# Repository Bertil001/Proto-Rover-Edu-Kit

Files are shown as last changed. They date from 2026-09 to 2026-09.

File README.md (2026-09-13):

# 🚀 P.R.E.K. (Proto-Rover Edu-Kit)

**P.R.E.K.** est une plateforme d'exploration robotique 6x6 open-source conçue pour l'apprentissage et le prototypage avancé. Basé sur un microcontrôleur ESP32 et un châssis "Rocker-Bogie", le rover embarque son propre serveur web tactile, une centrale inertielle 6-axes et une architecture logicielle asynchrone Dual-Core.

---

## ⚙️ Fonctionnalités Principales

* **Châssis Rocker-Bogie :** Suspension mécanique passive permettant de franchir des obstacles asymétriques tout en gardant la plateforme électronique stable.
* **Architecture Dual-Core (MicroPython) :**
  * **Core 0 :** Gestion du réseau, création du point d'accès Wi-Fi, serveur HTTP asynchrone et interface web (UI).
  * **Core 1 :** Cinématique de contrôle moteur (PWM à 1000 Hz), mixage Tank-Drive, rampe d'accélération et calcul trigonométrique de l'assiette.
* **Système Fail-Safe :** Arrêt d'urgence automatique en cas de perte de la trame réseau (délai > 500ms).
* **Interface "Tactical OS" :** IHM web full-responsive hébergée sur l'ESP32, avec vue éclatée SVG interactive et télémétrie en temps réel (Tangage, Roulis, RSSI Wi-Fi).

---

## 🛠️ Matériel Requis (BOM)

* **Microcontrôleur :** 1x ESP32 (WROOM-32)
* **Puissance :** 
  * 1x Batterie Li-Po (7.4V ou 11.1V)
  * 1x Module Buck Converter (12V > 5V) pour isoler le circuit logique
  * 2x Drivers moteur BTS7960 (Pont en H 43A)
* **Motricité :** 6x Micromoteurs N20 avec réducteurs + roues tout-terrain
* **Capteur :** 1x Centrale Inertielle MPU6050 (Accéléromètre / Gyroscope)
* **Sécurité :** Fusible automobile 10A et câblage de puissance adapté

---

## 📂 Arborescence du Projet

* `/src/` : Code source MicroPython embarqué sur l'ESP32.
  * `main.py` : Lanceur Dual-Core.
  * `core0_network.py` : Serveur réseau et code HTML/CSS/JS de l'interface.
  * `core1_motion.py` : Boucle cinématique et gestion matérielle (Moteurs & MPU).
  * `lib_mpu6050.py` : Pilote I2C pour le capteur inertiel.
* `/hardware/` : Fichiers de conception physique (Modèles 3D STEP/STL, Schémas de câblage).
* `/docs/` : Documentation d'ingénierie (Cahier des charges, plans de tests, bilan technique).

---

## 🚀 Démarrage Rapide (Quick Start)

### 1. Déploiement Logiciel
1. Flashez votre ESP32 avec le dernier firmware **MicroPython**.
2. Utilisez un IDE comme [Thonny](https://thonny.org/) ou l'outil **WebREPL** pour transférer l'intégralité du contenu du dossier `/src/` à la racine matérielle de l'ESP32.
3. Redémarrez le microcontrôleur.

### 2. Connexion et Pilotage
Une fois l'ESP32 alimenté, le rover génère son propre réseau autonome :
* **Réseau Wi-Fi (SSID) :** `ProtoRover_AP`
* **Mot de passe Wi-Fi :** *(Réseau ouvert)*
* **URL de l'Interface de Contrôle :** Ouvrez `http://192.168.4.1` sur le navigateur d'un smartphone ou d'un PC.

### 3. Maintenance Sans Fil (OTA)
Le P.R.E.K. intègre le protocole WebREPL pour la mise à jour du code sans câble USB :
* **Adresse WebSocket :** `ws://192.168.4.1:8266`
* **Mot de passe WebREPL :** `rover123`

---

## 📝 Licence
Ce projet est distribué sous la Licence MIT. Consultez le fichier `LICENSE` pour plus d'informations.

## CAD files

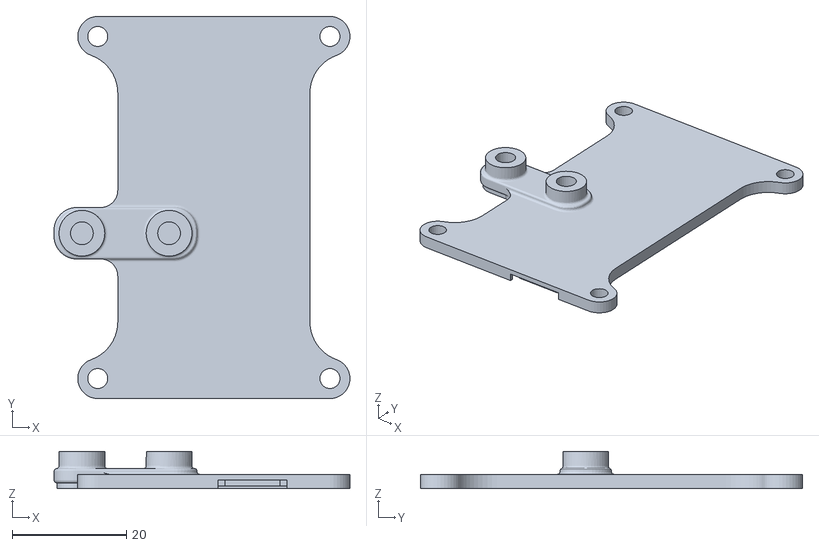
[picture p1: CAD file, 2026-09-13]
hardware/Box_Top_Convertisseur_REVA.stl
51.7 x 66.8 x 6.49

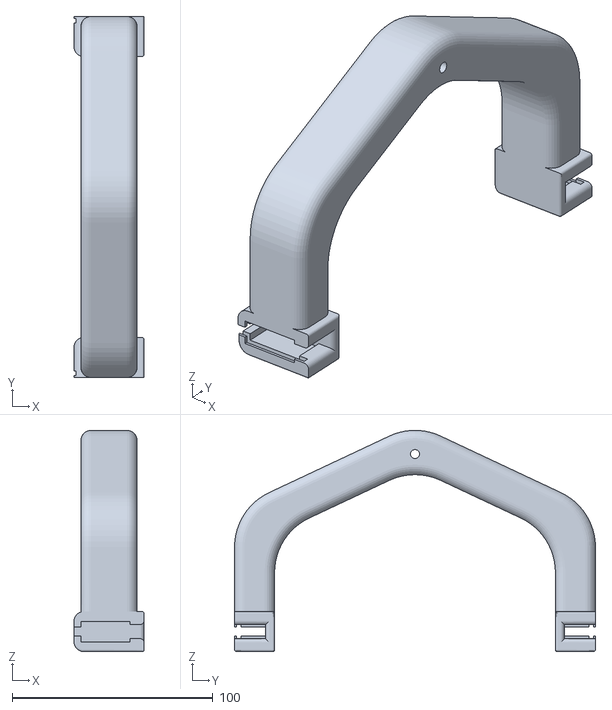
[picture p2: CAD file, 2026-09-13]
hardware/Pivot_Bogie_Left_REVA.stl
35.0 x 180.0 x 110.4

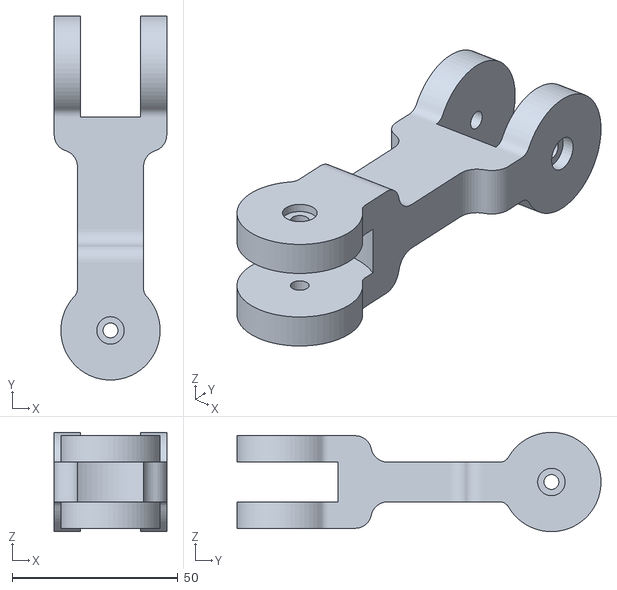
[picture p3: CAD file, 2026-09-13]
hardware/Differential_Link_R_REVA.stl
34.0 x 110.0 x 30.0

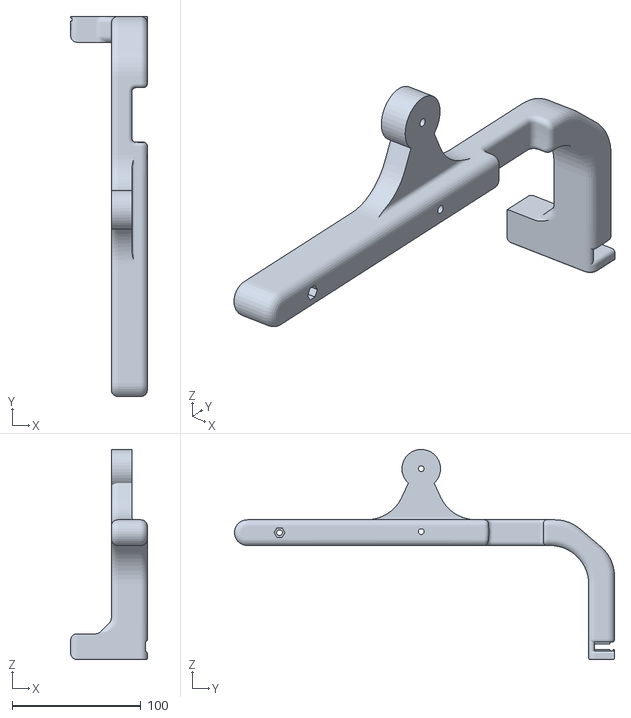
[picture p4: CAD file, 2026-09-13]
hardware/Arm_Rocker_Left_REVA.stl
59.6 x 294.9 x 163.0

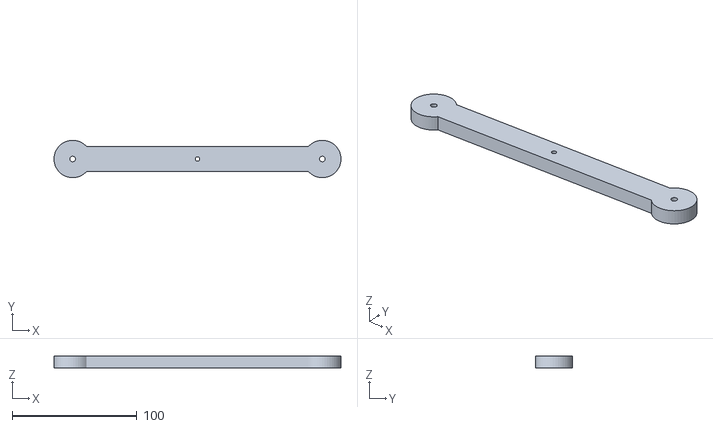
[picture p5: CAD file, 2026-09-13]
hardware/Differential_Bar_REVA.stl
230.3 x 30.0 x 10.0

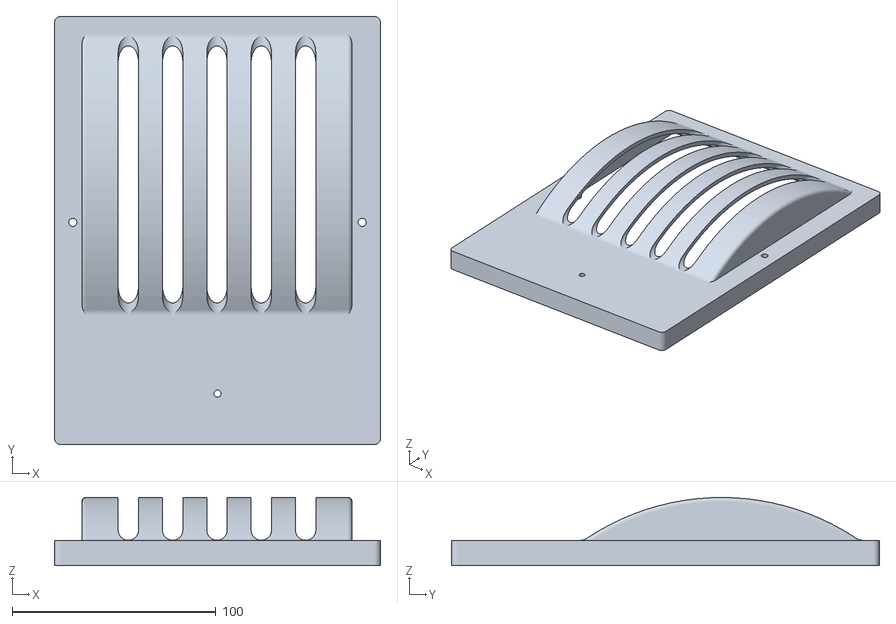
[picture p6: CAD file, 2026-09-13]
hardware/Box_Top_REVA.stl
160.0 x 210.0 x 33.4

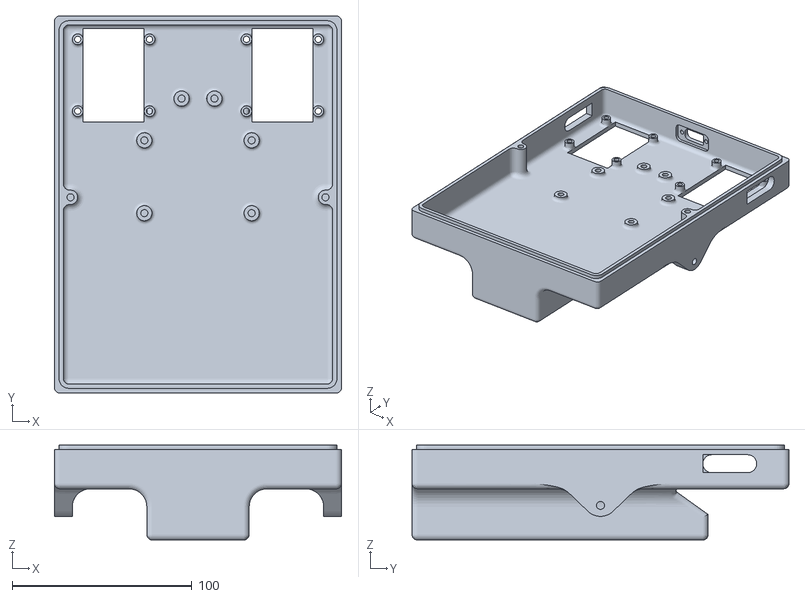
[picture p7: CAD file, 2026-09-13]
hardware/Box_Bottom_REVA.stl
160.0 x 210.0 x 52.9

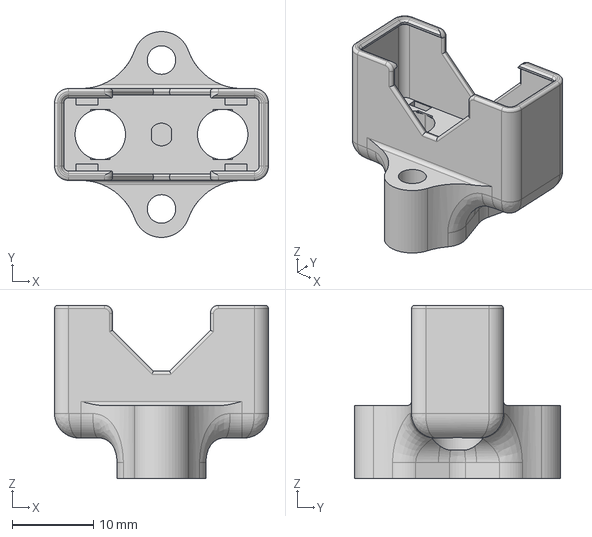
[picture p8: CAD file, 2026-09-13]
hardware/Support_Fusible.step
26.3 x 25.3 x 21.3 mm

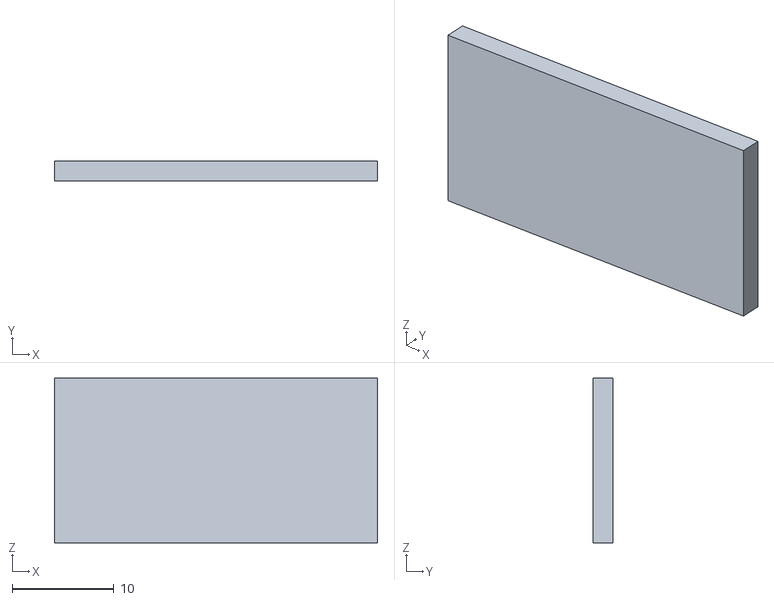
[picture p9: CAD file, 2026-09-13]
hardware/Motor_Retainer_REVA.stl
31.8 x 2.00 x 16.2

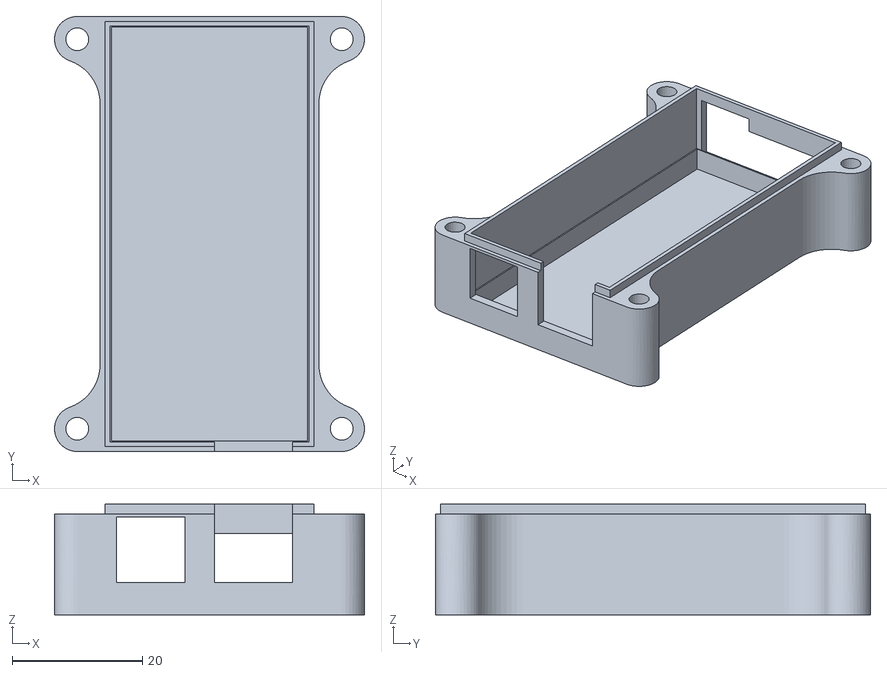
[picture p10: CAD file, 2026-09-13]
hardware/Box_Bottom_Convertisseur.stl
47.6 x 66.8 x 17.0

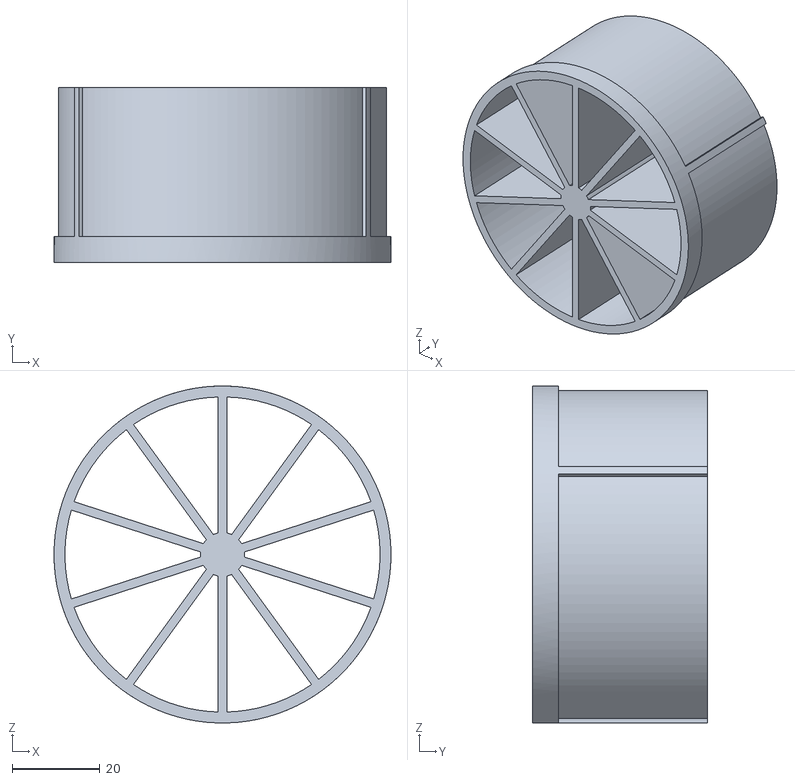
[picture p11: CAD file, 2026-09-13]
hardware/Jante_REVA.stl
76.9 x 40.0 x 76.9

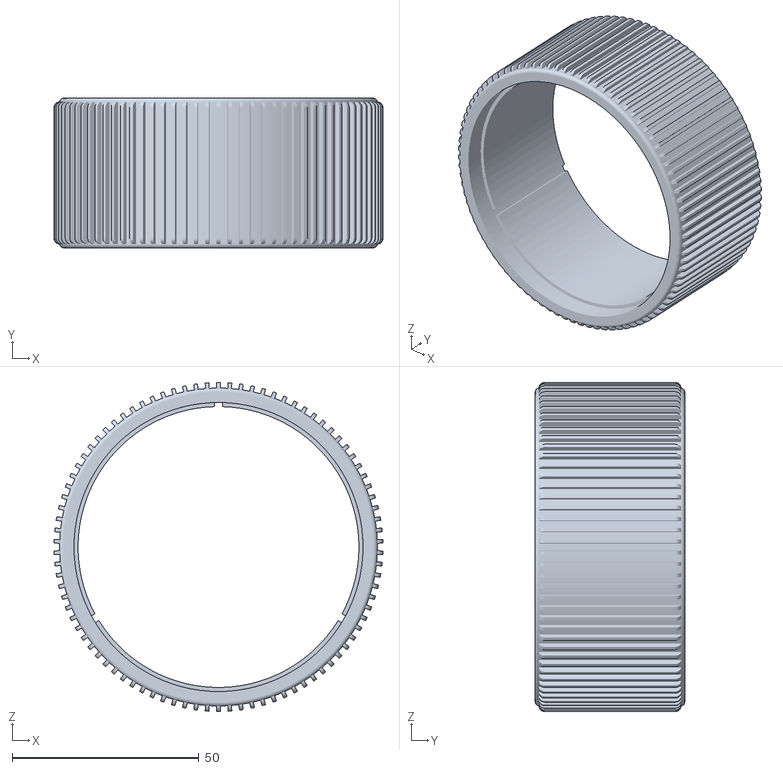
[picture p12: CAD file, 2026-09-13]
hardware/Pneu v11.stl
88.0 x 40.0 x 88.0

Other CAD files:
hardware/Pivot_Bogie_Right_REVA.stl
hardware/Arm_Rocker_Right_REVA.stl
hardware/Differential_Link_L_REVA.stl

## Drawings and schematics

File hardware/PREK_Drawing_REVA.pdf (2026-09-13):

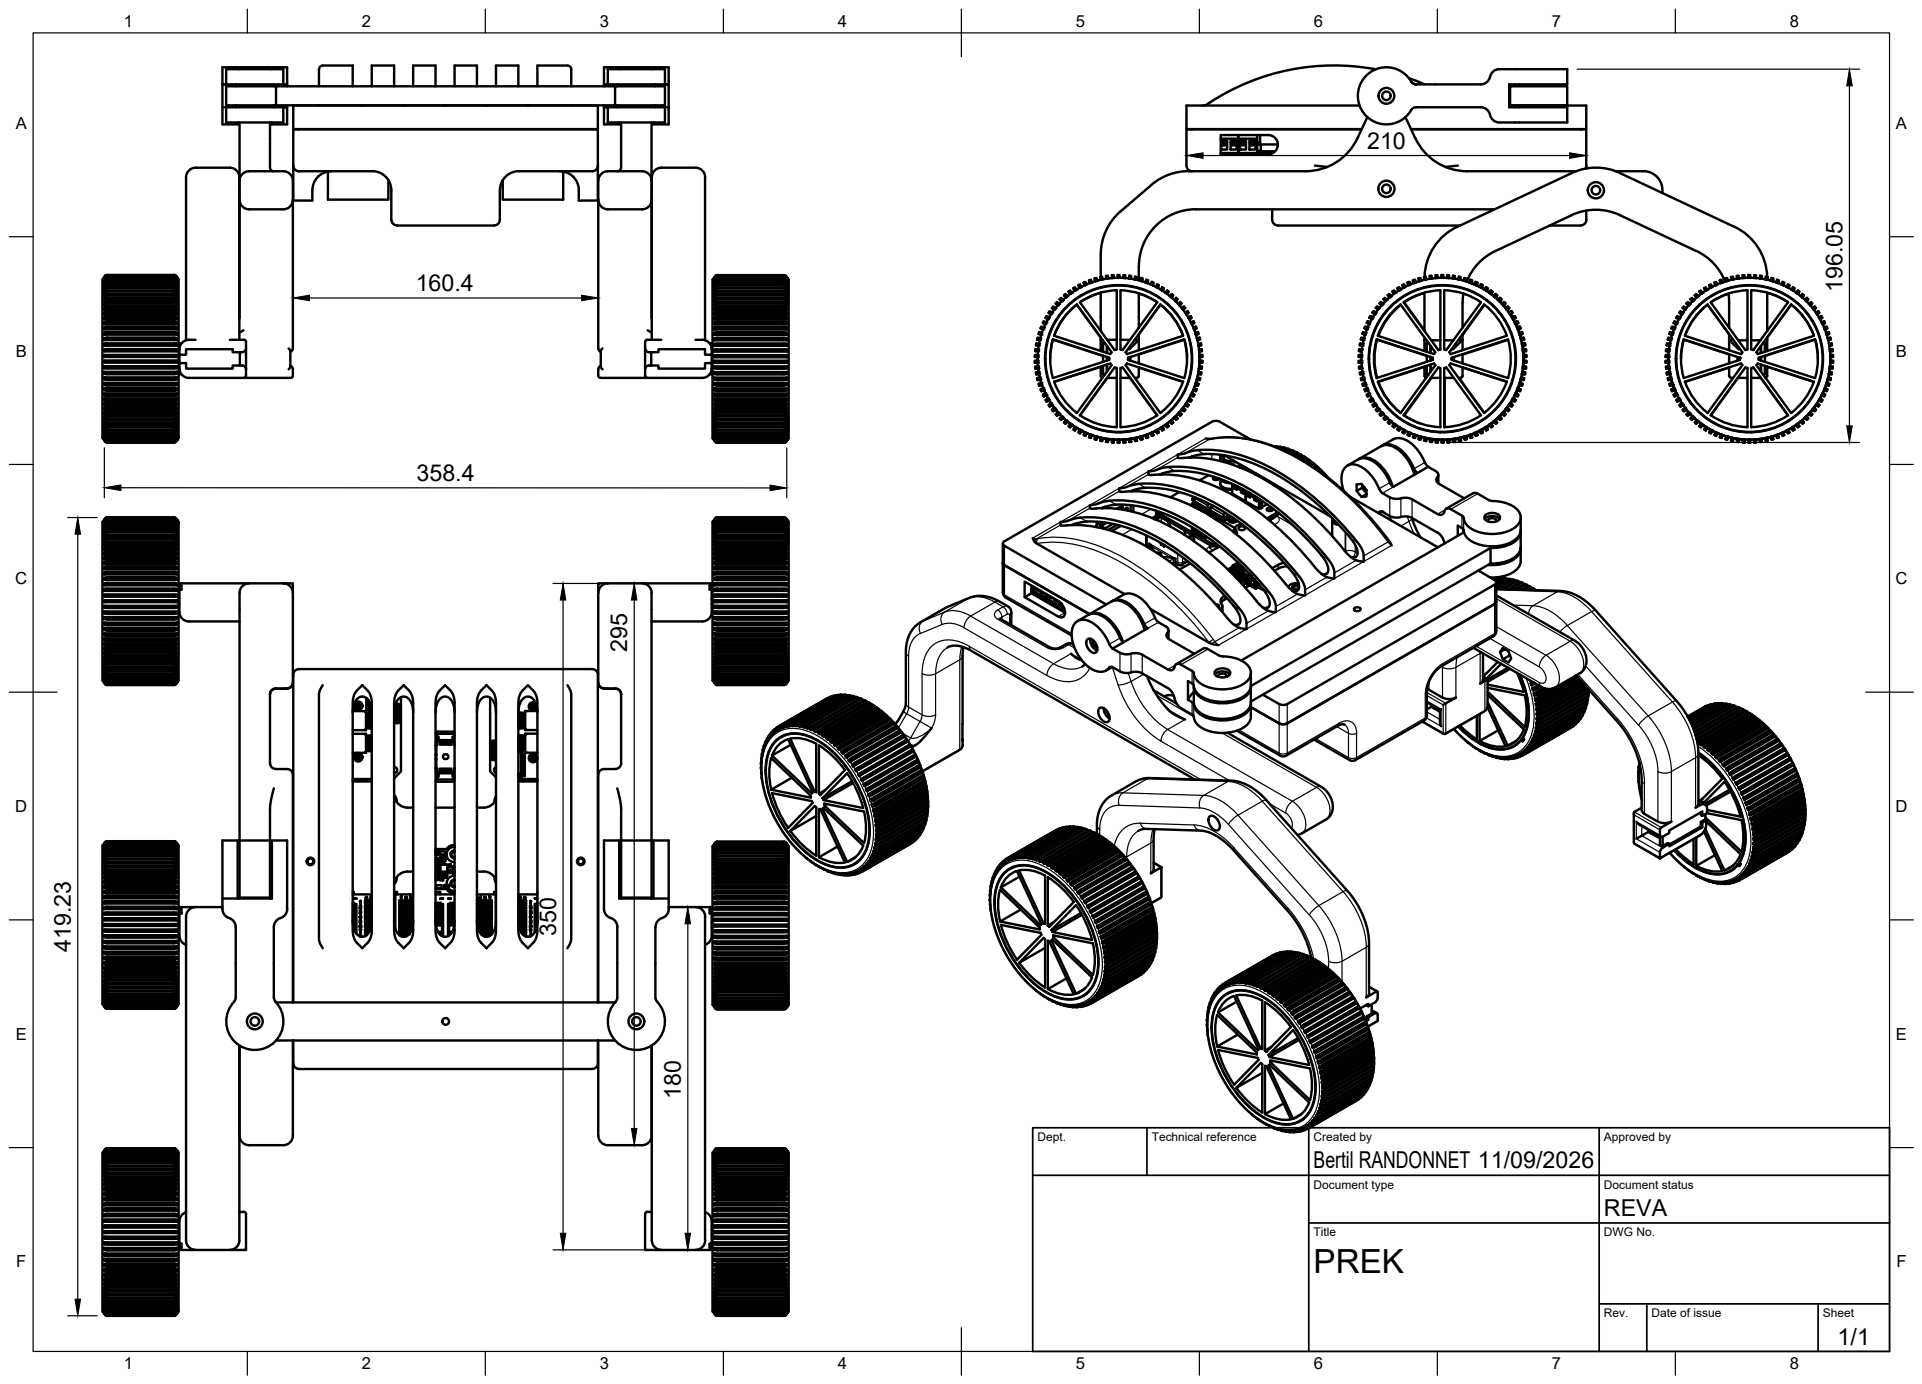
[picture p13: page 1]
Dept.; Technical reference; Created by; Approved by; Document type; Document status; Title; DWG No.; Rev.; Date of issue; Sheet; Bertil RANDONNET

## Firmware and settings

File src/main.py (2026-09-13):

# main.py - Point d'entrée principal
import _thread
import time
import core0_network
import core1_motion

# Création du dictionnaire partagé entre les deux cœurs
shared_state = {
    'speed': 0,        # Vitesse (-100 à 100)
    'turn': 0,         # Direction (-100 à 100)
    'timestamp': time.ticks_ms(), # Pour le Failsafe
    'angle_x': 0.0,
    'angle_y': 0.0
}

print("=== DÉMARRAGE DU PROTOROVER ===")

# 1. Lancement du Cœur 1 (Asservissement Moteurs) dans un Thread séparé
print("Lancement du Cœur 1...")
_thread.start_new_thread(core1_motion.run_motion_loop, (shared_state,))

# 2. Lancement du Cœur 0 (Réseau) sur le Thread principal
print("Lancement du Cœur 0...")
core0_network.run_network_loop(shared_state)

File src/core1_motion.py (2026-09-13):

import time
import math
from machine import Pin, PWM, I2C
from lib_mpu6050 import MPU6050

class MotionController:
    def __init__(self, l_fwd=12, l_rev=13, r_fwd=14, r_rev=27):
        # Initialisation des broches PWM pour le driver BTS7960
        self.lpwm_l = PWM(Pin(l_fwd), freq=1000, duty=0)
        self.rpwm_l = PWM(Pin(l_rev), freq=1000, duty=0)
        self.lpwm_r = PWM(Pin(r_fwd), freq=1000, duty=0)
        self.rpwm_r = PWM(Pin(r_rev), freq=1000, duty=0)

    def set_motors(self, speed_left, speed_right):
        MAX_DUTY = 1023 
        duty_l = int((abs(speed_left) / 100) * MAX_DUTY)
        duty_r = int((abs(speed_right) / 100) * MAX_DUTY)
        
        # Arrêt de toutes les broches avant d'appliquer la nouvelle direction
        self.lpwm_l.duty(0)
        self.rpwm_l.duty(0)
        self.lpwm_r.duty(0)
        self.rpwm_r.duty(0)
        
        # Moteur Gauche
        if speed_left > 0:
            self.lpwm_l.duty(duty_l)
        elif speed_left < 0:
            self.rpwm_l.duty(duty_l)
            
        # Moteur Droit
        if speed_right > 0:
            self.lpwm_r.duty(duty_r)
        elif speed_right < 0:
            self.rpwm_r.duty(duty_r)

def run_motion_loop(*args):
    print("[Core 1] Démarrage de la boucle de contrôle et télémétrie 6-axes !")
    motion = MotionController()
    state = args[0]
    
    # --- 1. Initialisation du capteur MPU6050 ---
    try:
        ligne_i2c = I2C(0, scl=Pin(22), sda=Pin(21), freq=100000)
        capteur = MPU6050(ligne_i2c)
        capteur_ok = True
    except Exception as e:
        print("[Core 1] ERREUR : MPU6050 introuvable !", e)
        capteur_ok = False
        
    # --- 2. Fonction pour calculer les angles X et Y ---
    def get_angles():
        if not capteur_ok: return 0.0, 0.0
        
        x, y, z = capteur.get_accel()
        
        # Correction vitale pour les nombres négatifs (complément à 2)
        if x > 32767: x -= 65536
        if y > 32767: y -= 65536
        if z > 32767: z -= 65536
        
        # Calcul trigonométrique (Tangage et Roulis)
        angle_x = math.atan2(-x, math.sqrt(y * y + z * z)) * (180.0 / math.pi)
        angle_y = math.atan2(y, math.sqrt(x * x + z * z)) * (180.0 / math.pi)
        
        return angle_x, angle_y

    compteur_affichage = 0

    # --- 3. Boucle principale ---
    while True:
        # Lecture des ordres moteurs sécurisée par .get()
        vitesse = state.get('speed', 0)
        direction = state.get('turn', 0)
        
        # Mixage des vitesses pour les chenilles/roues
        vitesse_gauche = vitesse + direction
        vitesse_droite = vitesse - direction
        
        # Action sur les moteurs
        motion.set_motors(vitesse_gauche, vitesse_droite)
        
        # Récupération et sauvegarde des deux angles pour le Core 0
        ax, ay = get_angles()
        state['angle_x'] = ax
        state['angle_y'] = ay
        
        # Affichage console (1 fois par seconde environ)
        compteur_affichage += 1
        if compteur_affichage >= 20: 
            print(f"| Tangage(X): {ax:>6.1f}° | Roulis(Y): {ay:>6.1f}° | Mot: G={vitesse_gauche}% D={vitesse_droite}% |")
            compteur_affichage = 0
            
        time.sleep(0.05)

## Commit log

2026-09-13 Initialize main.py for multi-threaded operation
    This script initializes a shared state dictionary for speed, turn, timestamp, and angles, and starts two threads for motion control and network operations.
2026-09-13 Create Notice de montage
